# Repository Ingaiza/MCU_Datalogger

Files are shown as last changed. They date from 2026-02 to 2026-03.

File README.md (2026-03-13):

# MCU Datalogger Board

## Overview
This repository contains the KiCad PCB design files for a custom MCU Datalogger board. This board integrates robust non-volatile memory, real-time tracking capabilities, and essential communication interfaces. It serves as a reliable hardware foundation for capturing, storing, and transmitting sensor data in embedded systems.

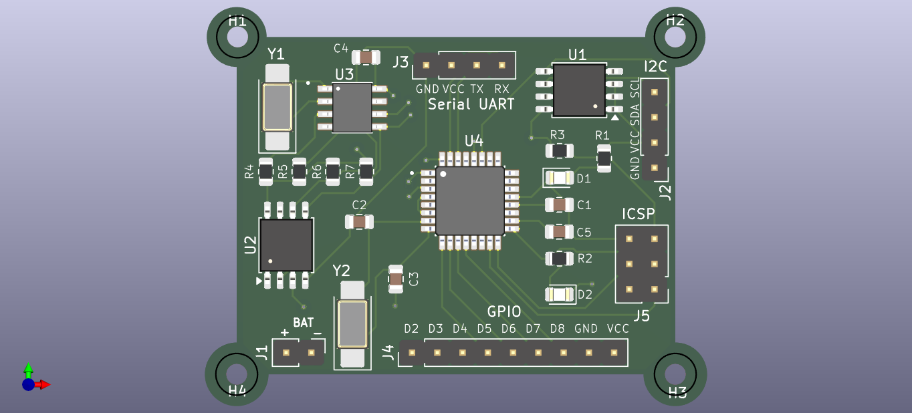
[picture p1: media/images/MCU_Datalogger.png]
Board Top View


## Hardware Features

* **Microcontroller**: Powered by the ATMEGA328P-AU 8-bit AVR microcontroller, running on a 16MHz external crystal.
* **Timekeeping**: Features an integrated DS1337S Real-Time Clock (RTC) equipped with a dedicated 32.768kHz crystal for precise timestamping of logged data.
* **Memory & Storage**: 
    * Dual 24LC1025 EEPROMs (U1 and U2) provide extensive, reliable onboard data storage over the I2C bus.
* **User Interface & Expansion**:
    * Dedicated headers for standard communication protocols: I2C and Serial UART.
    * Accessible GPIO breakout header for rapid prototyping and connecting external sensors.
    * Standard 6-pin ICSP header for direct programming and bootloader flashing.
    * Dual status LEDs (D1, D2) for easy visual debugging.

## Visuals & Documentation

### 3D Slanted View
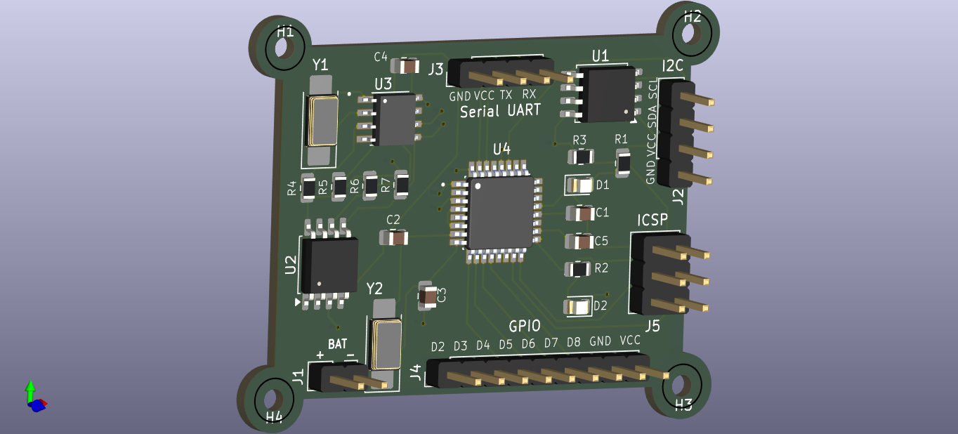
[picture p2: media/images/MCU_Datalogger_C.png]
Board 3D Slanted View


### Board Layout & Routing
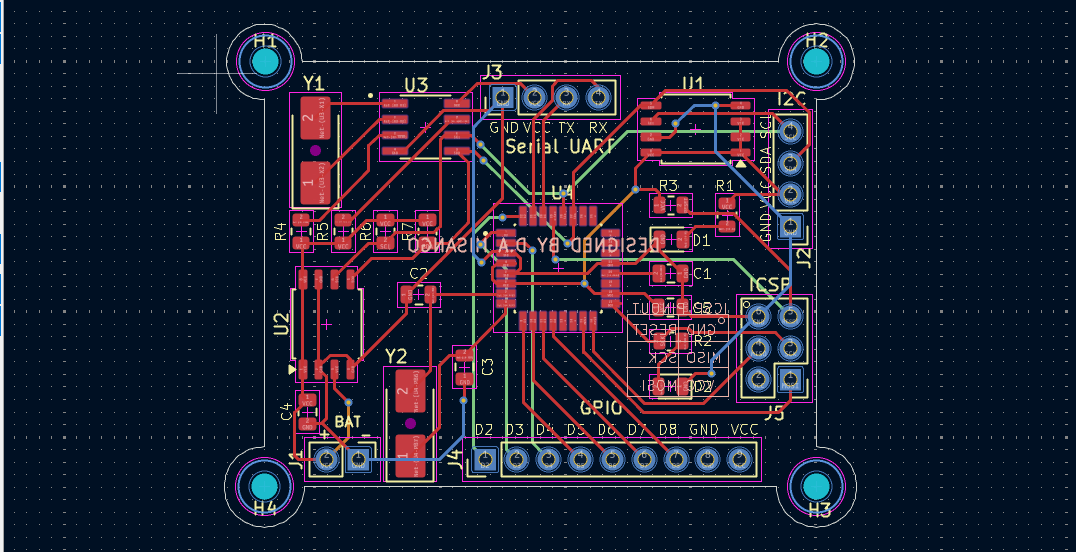
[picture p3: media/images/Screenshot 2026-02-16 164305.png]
Layout View 1

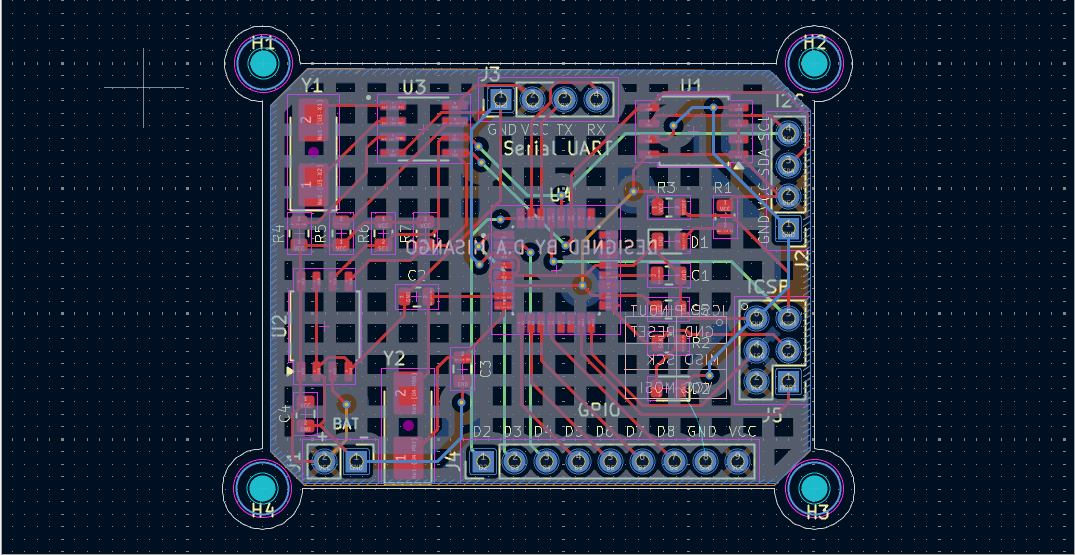
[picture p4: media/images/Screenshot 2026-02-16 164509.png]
Layout View 2


### Schematic
The complete circuit design can be viewed here: [Schematic PDF](media/schematic.pdf)

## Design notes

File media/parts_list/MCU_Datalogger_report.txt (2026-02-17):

PCB statistics report
=====================
- Date: 2/16/2026 8:00:12 PM
- Project: MCU_Datalogger
- Board name: MCU_Datalogger

Board
-----
- Width: 50.4950 mm
- Height: 40.1595 mm
- Area: 1587.5018 mm²

Pads
----
- Through hole: 25
- SMD: 88
- Connector: 0
- NPTH: 4

Vias
----
- Through vias: 16
- Blind/buried: 0
- Micro vias: 0

Components
----------

| | Front Side | Back Side | Total |
|---|---|---|---|
|THT: | 5 | 0 | 5 |
|SMD: | 20 | 0 | 20 |
|Unspecified:  | 4 | 0 | 4 |
|Total: | 29 | 0 | 29 |

Drill holes
-----------

| Count | Shape | X Size | Y Size | Plated | Via/Pad | Start Layer | Stop Layer |
|---|---|---|---|---|---|---|---|
| 25 | Round | 1.0000 mm | 1.0000 mm | PTH | Pad | F.Cu | B.Cu |
| 16 | Round | 0.3000 mm | 0.3000 mm | PTH | Via | F.Cu | B.Cu |
| 4 | Round | 2.1000 mm | 2.1000 mm | NPTH | Pad | F.Cu | B.Cu |

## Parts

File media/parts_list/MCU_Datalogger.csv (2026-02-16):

Id | Designator | Footprint | Quantity | Designation | Supplier and ref
1 | R5,R4,R3 | R_0805_2012Metric | 3 | 10k
2 | U2,U1 | SOIC-8_5.3x5.3mm_P1.27mm | 2 | 24LC1025
3 | J3,J2 | PinHeader_1x04_P2.54mm_Vertical | 2 | Conn_01x04_Pin
4 | D2,D1 | LED_0805_2012Metric | 2 | LED
5 | R1,R2 | R_0805_2012Metric | 2 | 330
6 | Y1 | Crystal_SMD_5032-2Pin_5.0x3.2mm_HandSoldering | 1 | 32.768kHz
7 | C4,C1 | C_0805_2012Metric | 2 | 0.1uF
8 | Y2 | Crystal_SMD_5032-2Pin_5.0x3.2mm_HandSoldering | 1 | 16MHz
9 | U3 | SOIC127P600X175-8N | 1 | DS1337S_
10 | C5 | C_0805_2012Metric | 1 | 100nF
11 | J1 | PinHeader_1x02_P2.54mm_Vertical | 1 | Conn_01x02_Pin
12 | C2,C3 | C_0805_2012Metric | 2 | 22pF
13 | R6,R7 | R_0805_2012Metric | 2 | 4.2k
14 | J4 | PinHeader_1x09_P2.54mm_Vertical | 1 | Conn_01x09_Pin
15 | J5 | PinHeader_2x03_P2.54mm_Vertical | 1 | Conn_02x03_Odd_Even
16 | U4 | QFP80P900X900X120-32N | 1 | ATMEGA328P-AU

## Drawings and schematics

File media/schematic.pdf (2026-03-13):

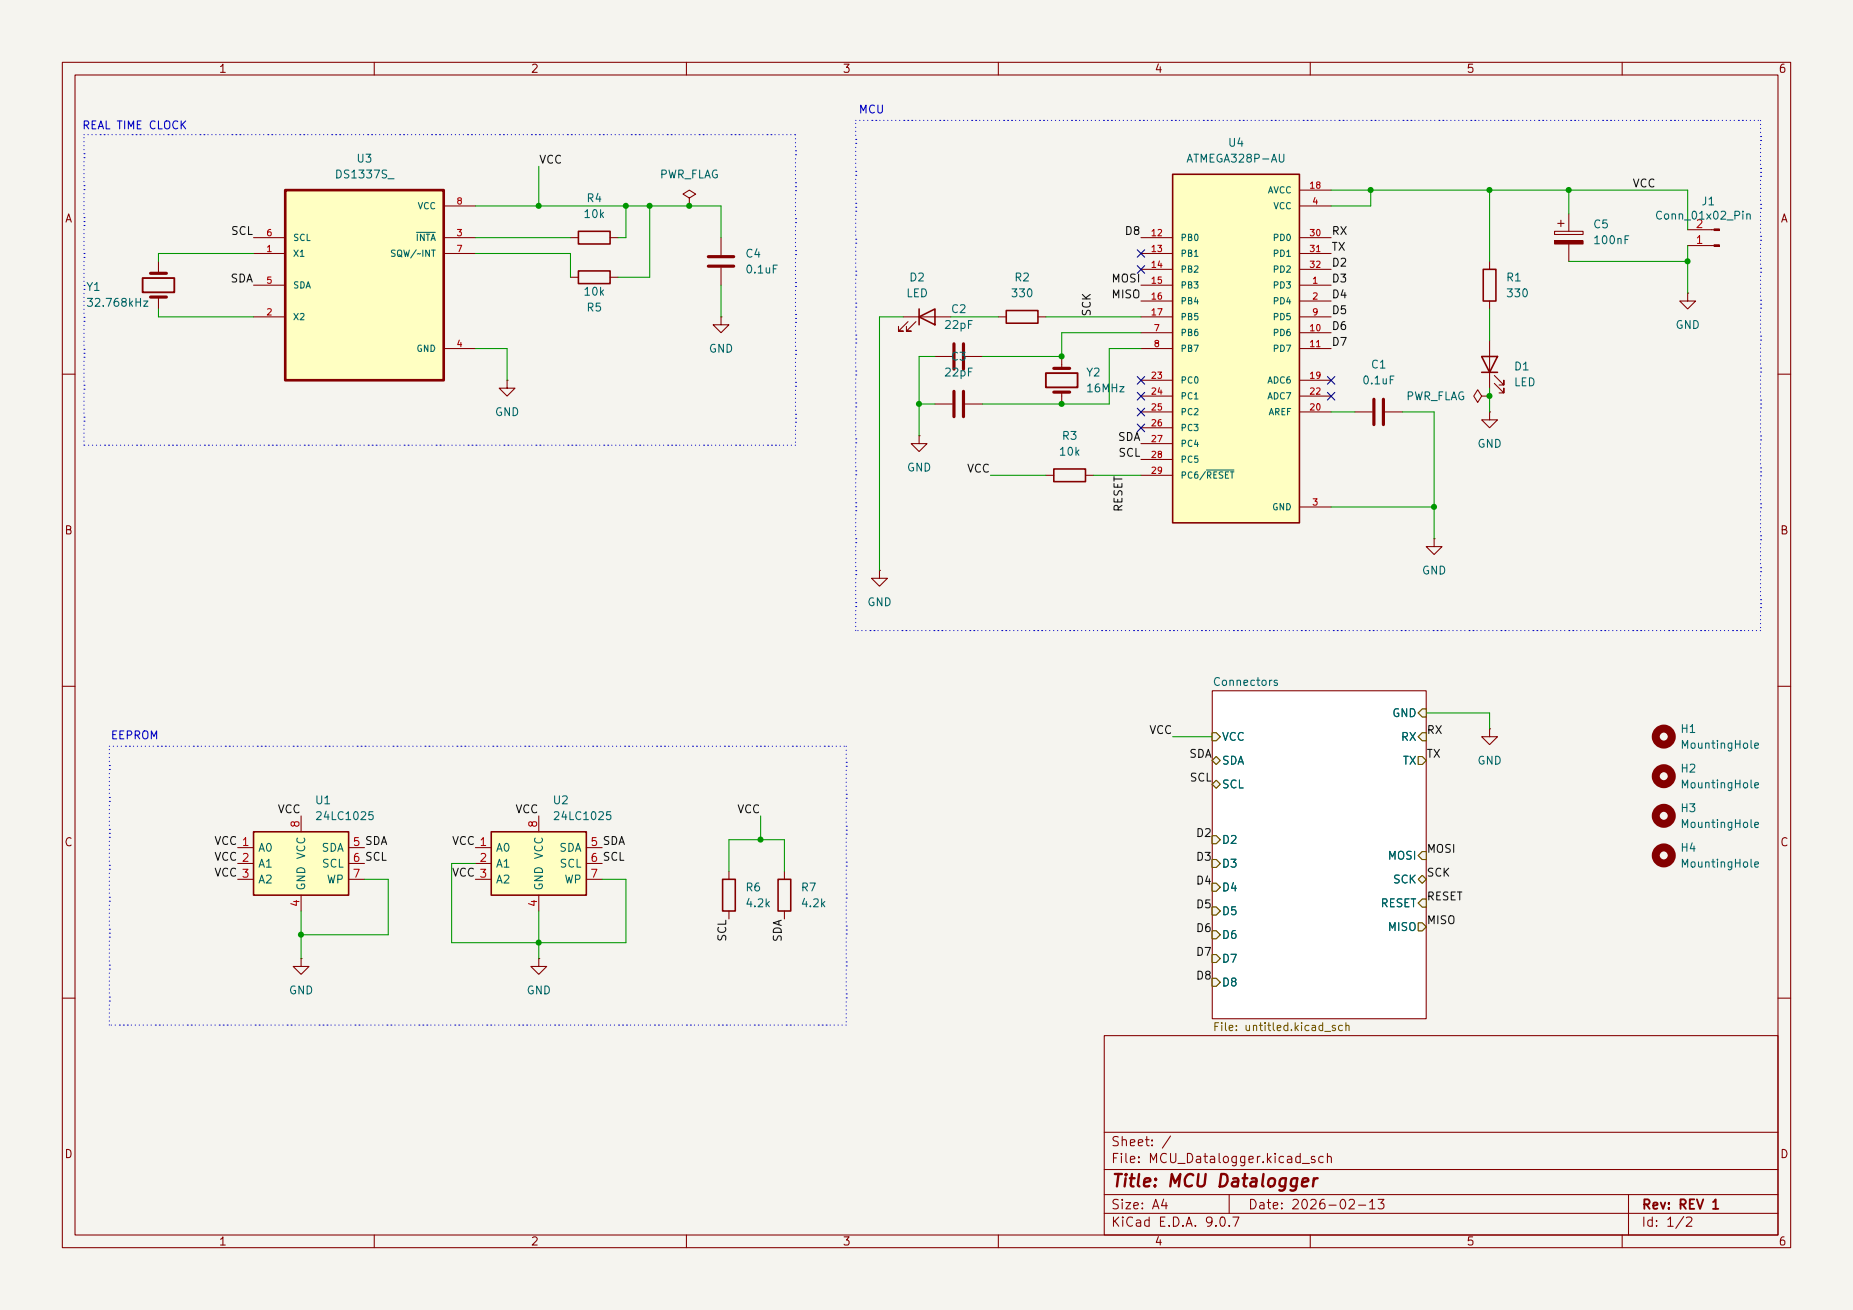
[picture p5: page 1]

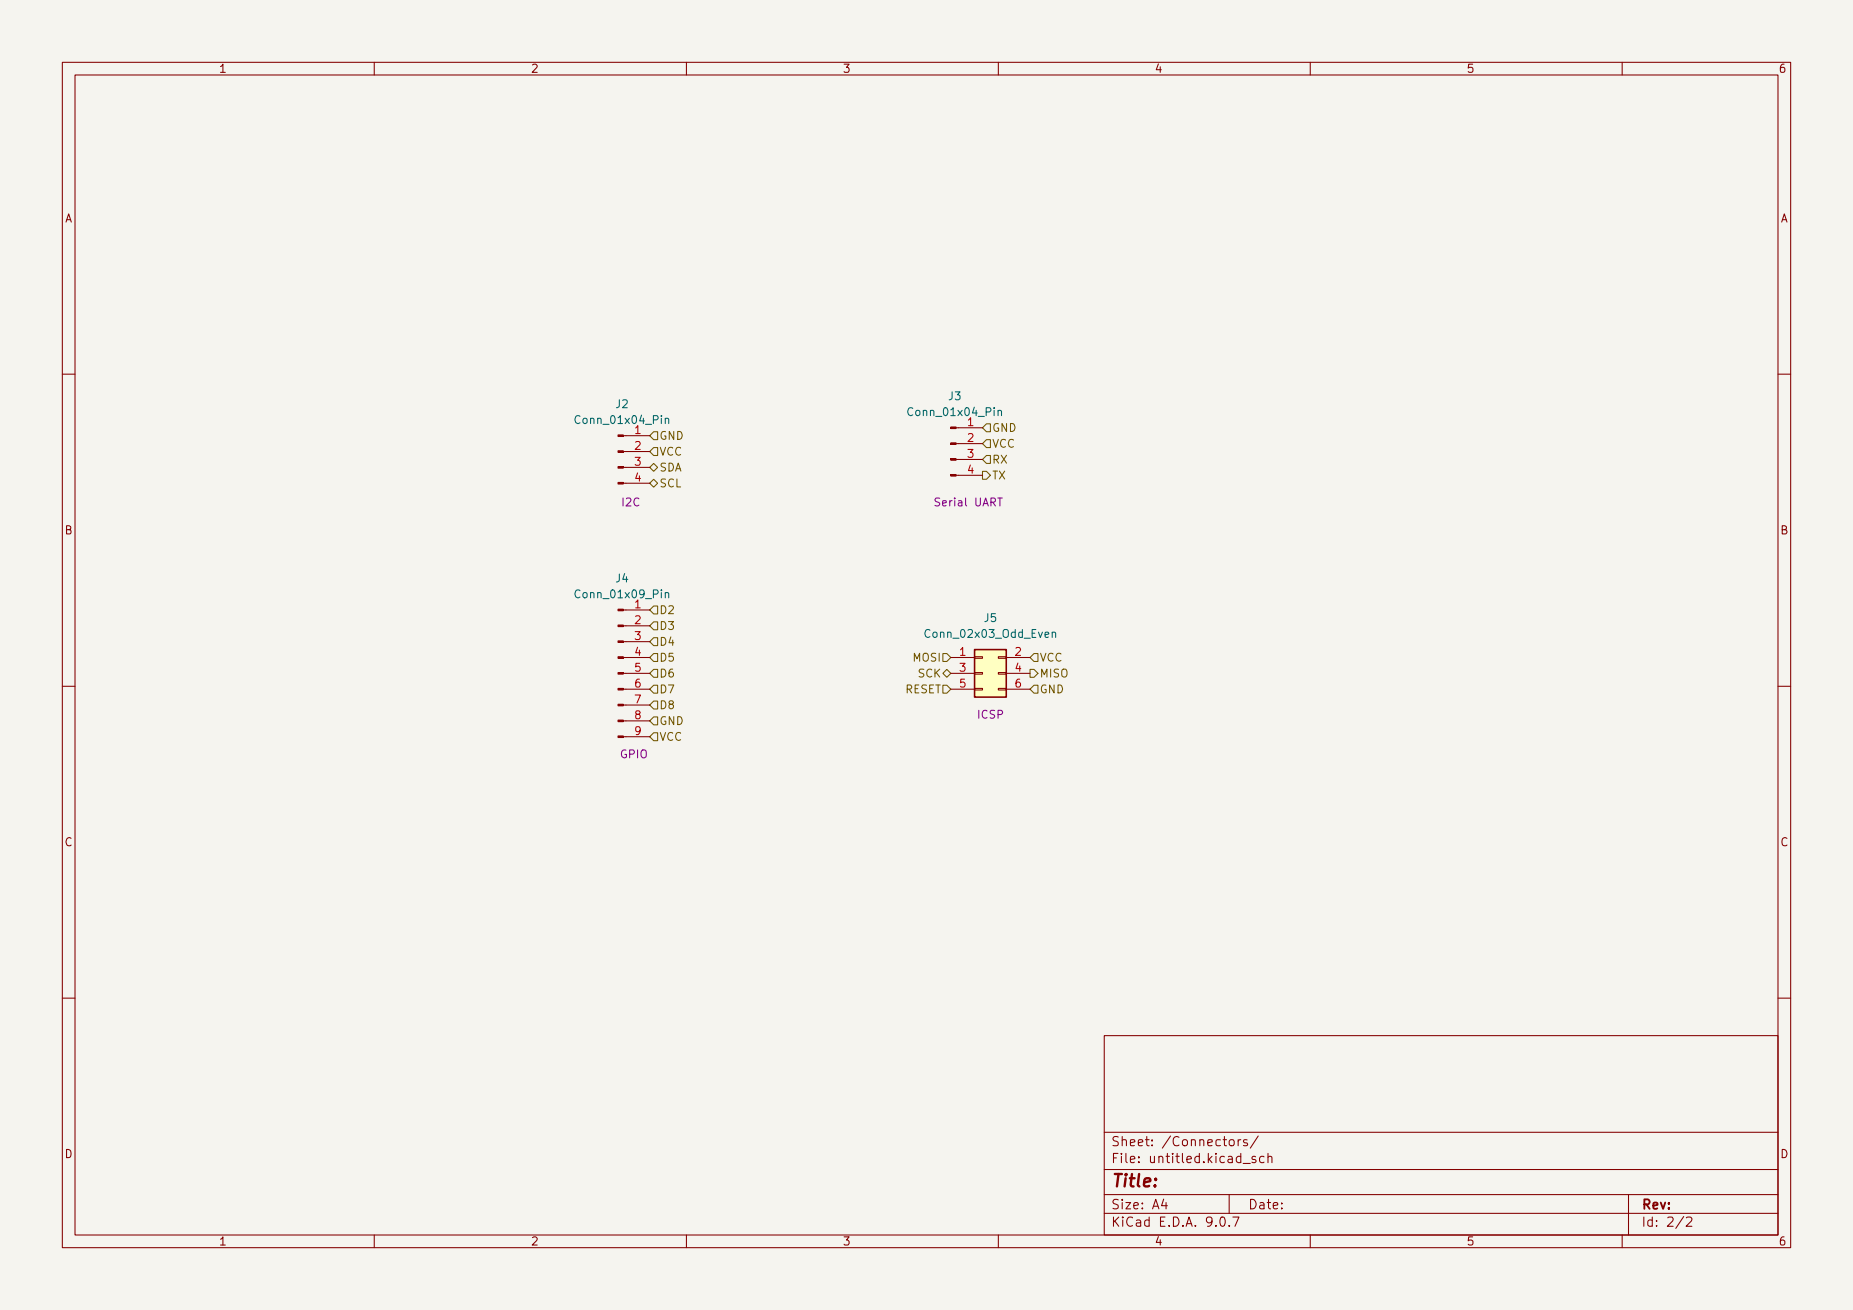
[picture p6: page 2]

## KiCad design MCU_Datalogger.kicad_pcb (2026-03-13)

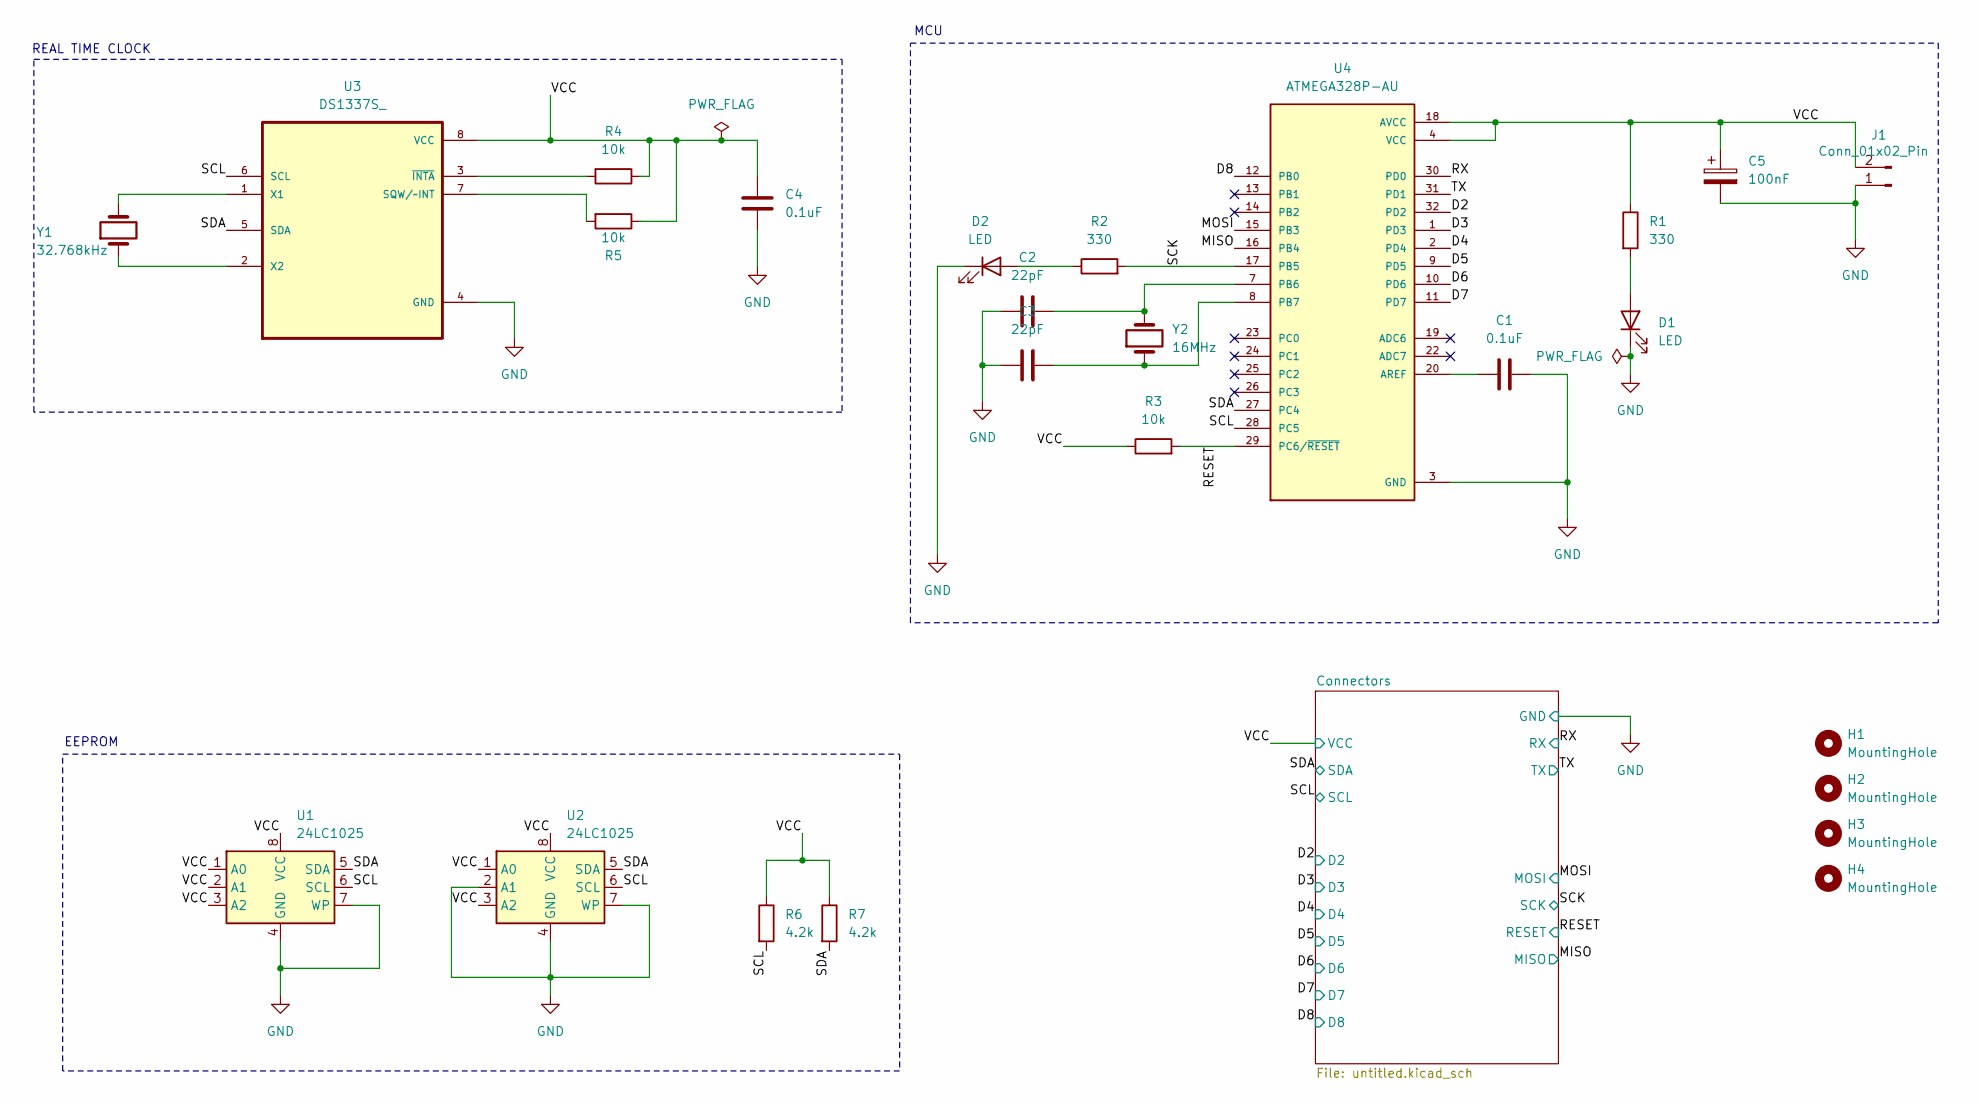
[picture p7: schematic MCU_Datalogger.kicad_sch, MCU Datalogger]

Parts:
C1, C4: 0.1uF; C_0805_2012Metric
C2, C3: 22pF; C_0805_2012Metric
C5: 100nF; C_0805_2012Metric
D1, D2: LED; LED_0805_2012Metric
H1, H2, H3, H4: MountingHole; MountingHole_2.1mm
J1: Conn_01x02_Pin; PinHeader_1x02_P2.54mm_Vertical
R1, R2: 330; R_0805_2012Metric
R3, R4, R5: 10k; R_0805_2012Metric
R6, R7: 4.2k; R_0805_2012Metric
U1, U2: 24LC1025; SOIC-8_5.3x5.3mm_P1.27mm
U3: DS1337S_; SOIC127P600X175-8N
U4: ATMEGA328P-AU; QFP80P900X900X120-32N; PARTREV 8271A
Y1: 32.768kHz; Crystal_SMD_5032-2Pin_5.0x3.2mm_HandSoldering
Y2: 16MHz; Crystal_SMD_5032-2Pin_5.0x3.2mm_HandSoldering

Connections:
/D2: U4.32 (PD2); also elsewhere on the board
/D3: U4.1 (PD3); also elsewhere on the board
/D4: U4.2 (PD4); also elsewhere on the board
/D5: U4.9 (PD5); also elsewhere on the board
/D6: U4.10 (PD6); also elsewhere on the board
/D7: U4.11 (PD7); also elsewhere on the board
/D8: U4.12 (PB0); also elsewhere on the board
/MISO: U4.16 (PB4); also elsewhere on the board
/MOSI: U4.15 (PB3); also elsewhere on the board
/RESET: R3.2, U4.29 (PC6/~RESET); also elsewhere on the board
/RX: U4.30 (PD0); also elsewhere on the board
/SCK: R2.2, U4.17 (PB5); also elsewhere on the board
/SCL: R6.2, U1.6 (SCL), U2.6 (SCL), U3.6 (SCL), U4.28 (PC5); also elsewhere on the board
/SDA: R7.2, U1.5 (SDA), U2.5 (SDA), U3.5 (SDA), U4.27 (PC4); also elsewhere on the board
/TX: U4.31 (PD1); also elsewhere on the board
GND: C1.1, C2.1, C3.1, C4.2, C5.2, D1.1 (K), D2.1 (K), J1.1, U1.4 (GND), U1.7 (WP), U2.2 (A1), U2.4 (GND), U2.7 (WP), U3.4 (GND), U4.3 (GND), U4.5 (GND), U4.21 (GND); also elsewhere on the board
unnamed: D1.2 (A), R1.2
unnamed: D2.2 (A), R2.1
unnamed: R5.2, U3.7 (SQW/~INT)
unnamed: U3.1 (X1), Y1.2
unnamed: U3.2 (X2), Y1.1
unnamed: R4.2, U3.3 (~INTA)
unnamed: C1.2, U4.20 (AREF)
unnamed: C2.2, U4.7 (PB6), Y2.2
unnamed: C3.2, U4.8 (PB7), Y2.1
VCC: C4.1, C5.1, J1.2, R1.1, R3.1, R4.1, R5.1, R6.1, R7.1, U1.1 (A0), U1.2 (A1), U1.3 (A2), U1.8 (VCC), U2.1 (A0), U2.3 (A2), U2.8 (VCC), U3.8 (VCC), U4.4 (VCC), U4.6 (VCC), U4.18 (AVCC); also elsewhere on the board

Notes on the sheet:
REAL TIME CLOCK
MCU
EEPROM

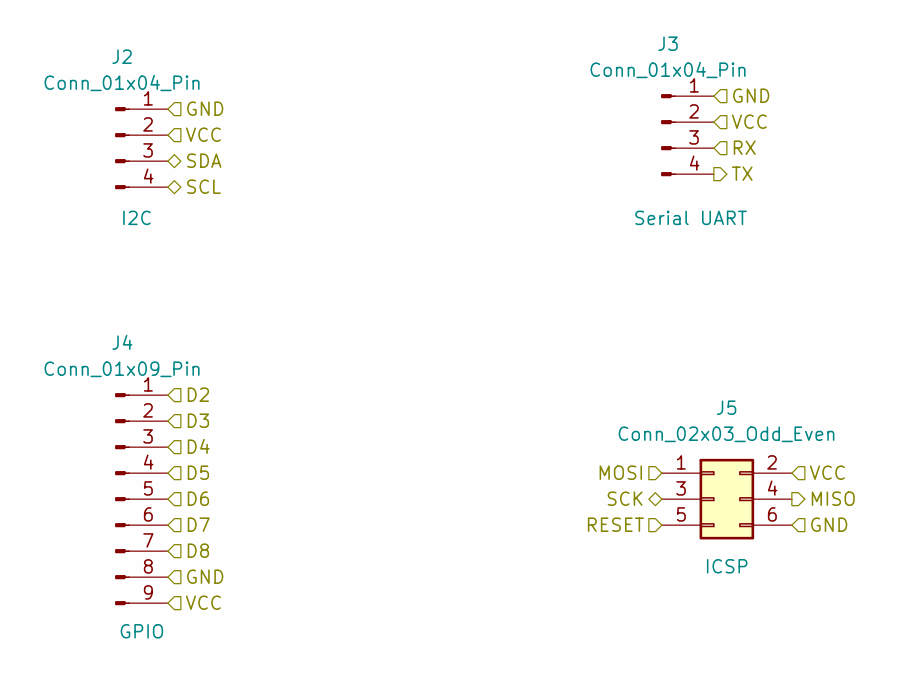
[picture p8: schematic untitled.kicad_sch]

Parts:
J2, J3: Conn_01x04_Pin; PinHeader_1x04_P2.54mm_Vertical
J4: Conn_01x09_Pin; PinHeader_1x09_P2.54mm_Vertical
J5: Conn_02x03_Odd_Even; PinHeader_2x03_P2.54mm_Vertical

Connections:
/D2: J4.1; also elsewhere on the board
/D3: J4.2; also elsewhere on the board
/D4: J4.3; also elsewhere on the board
/D5: J4.4; also elsewhere on the board
/D6: J4.5; also elsewhere on the board
/D7: J4.6; also elsewhere on the board
/D8: J4.7; also elsewhere on the board
/MISO: J5.4; also elsewhere on the board
/MOSI: J5.1; also elsewhere on the board
/RESET: J5.5; also elsewhere on the board
/RX: J3.3; also elsewhere on the board
/SCK: J5.3; also elsewhere on the board
/SCL: J2.4; also elsewhere on the board
/SDA: J2.3; also elsewhere on the board
/TX: J3.4; also elsewhere on the board
GND: J2.1, J3.1, J4.8, J5.6; also elsewhere on the board
VCC: J2.2, J3.2, J4.9, J5.2; also elsewhere on the board

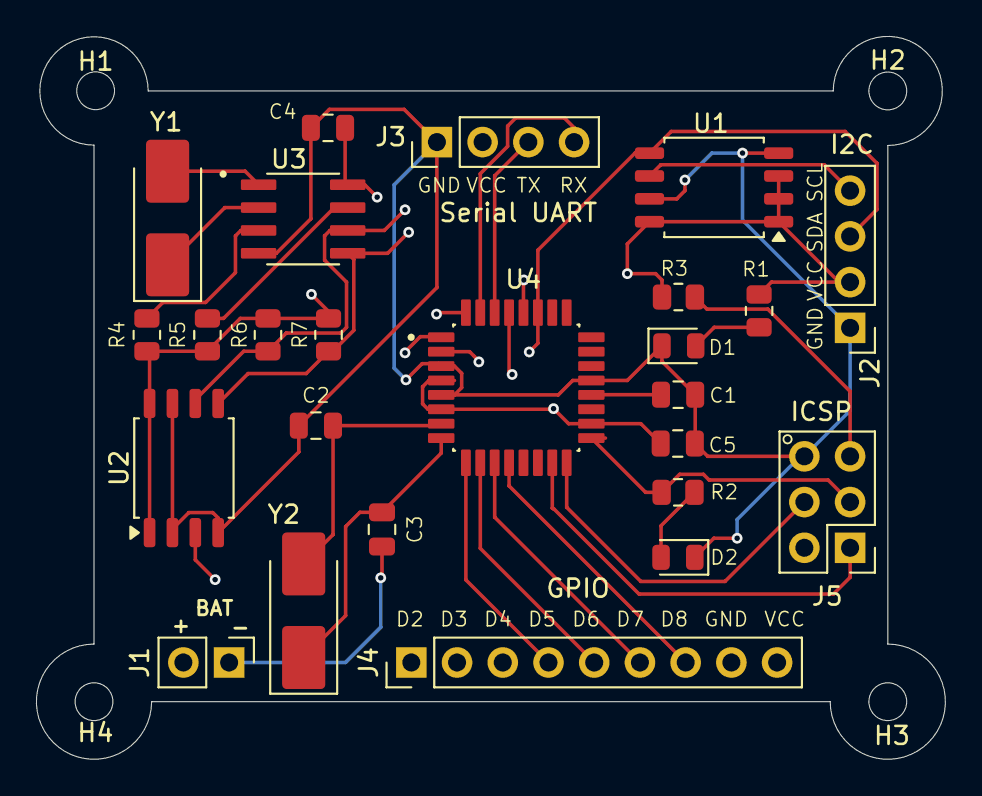
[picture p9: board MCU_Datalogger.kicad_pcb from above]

Board: 4 copper layers, 50.5 x 40.2 mm, 29 parts (0 on the bottom side), 26 nets.

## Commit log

2026-02-13 Created Project folder
    [MCU_Datalogger.kicad_pcb, MCU_Datalogger.kicad_sch]
2026-02-14 Completed Schematic
2026-02-14 Completed PCB Setup and Design
    [MCU_Datalogger.kicad_pcb, untitled.kicad_sch]
2026-02-14 Fixed silkscreen text overlapp
    [MCU_Datalogger.kicad_pcb, MCU_Datalogger.kicad_sch]
2026-02-14 edited .gitignore
    [MCU_Datalogger.kicad_pcb]
2026-02-16 Fixed RX TX misconnections
    [MCU_Datalogger.kicad_pcb, MCU_Datalogger.kicad_sch]
2026-02-16 Edited BAT footprint placement and silkscreen info
    [MCU_Datalogger.kicad_pcb]
2026-02-16 4 Layer board setup
    [MCU_Datalogger.kicad_pcb]
2026-02-16 Completed 4 Layer PCB Layout
    [MCU_Datalogger.csv, MCU_Datalogger.kicad_pcb]
2026-02-16 Edited Copper fills
    [MCU_Datalogger.kicad_pcb]
2026-02-17 Fixed C4 Decoupling capacitor placement and added keep-out areas on Crystal Y1 & Y2 footprint areas
2026-03-13 Added README
    [MCU_Datalogger.csv, MCU_Datalogger.kicad_pcb]
2026-03-13 zone fill to solid
    [MCU_Datalogger.kicad_pcb]
